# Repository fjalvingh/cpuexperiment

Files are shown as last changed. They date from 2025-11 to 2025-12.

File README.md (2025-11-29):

# Experiments with a am29xx based CPU

The am29xx series of bitslice CPU parts were a big thing when they arrived, and they have been used in many vintage designs. I find them interesting because they are still reasonably simple to understand, and they do replace a large amount of TTL logic for a homebrew CPU. I got a few of these parts from different places and decided to play with them to get an idea on how they work.

To do that the plan is to build some parts for a real CPU. It is not intended to be finished, it is intended to teach me and help me understand these parts, and to help me understand what is important in a CPU design using them.

## Process

NONE OF THIS IS READY FOR ANYTHING!! DO NOT ORDER BOARDS, they will not work ;)

### The ALU, getting to know the am2901

I am starting with the ALU part as I got 4 am2901's in my parts bin ;) I want to make a 16 bit ALU out of them, and the 2901's would also contain the generic register set (r0..r15).
I did consider breadboarding that, but 16 bits is a lot of wires, reliable breadboards are pretty expensive, and I really, *really* did not feel like wiring that all up...
So instead I created a Kicad schematic hoping that I would not be too far off, and I created a PCB using the Autorouter to route most traces so that I would not waste time on that. It is a 2 layer board so making fixes for the mistakes I've undoubtedly made should not be too difficult.

The board has 4x am2901, some glue logic to detect condition codes, a lot of leds to show ALU function inputs, and two sockets for my [8 bit bus to hex display](https://github.com/fjalvingh/8bit-busdisplay) so that we can easily follow what is happening.

The board uses two 40 pin double row pin headers (female) as a connector to a later possible backplane, as these are cheap and relatively reliable. And they make it easy to exercise the board using an Arduino Mega 2560.

A picture of the completed board:

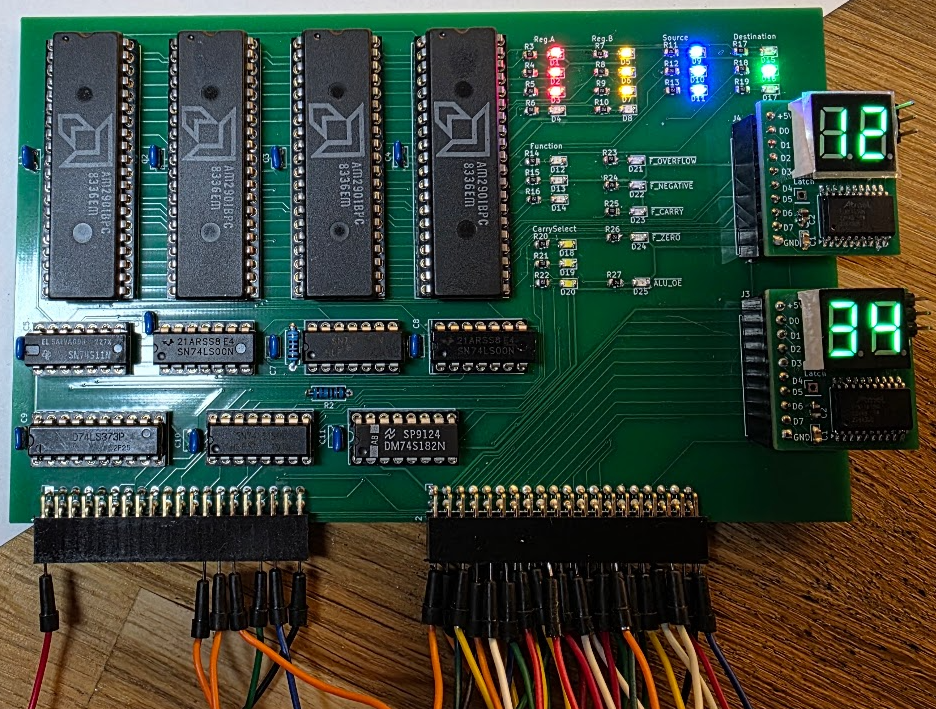
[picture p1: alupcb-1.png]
alu pcb


The wires into the connectors are breadboard patch wires, and they prove to be useless, so the next try is to make real pin header wires to the Arduino.

### Playing with the board

After creating proper cabling between the Arduino and the ALU board:

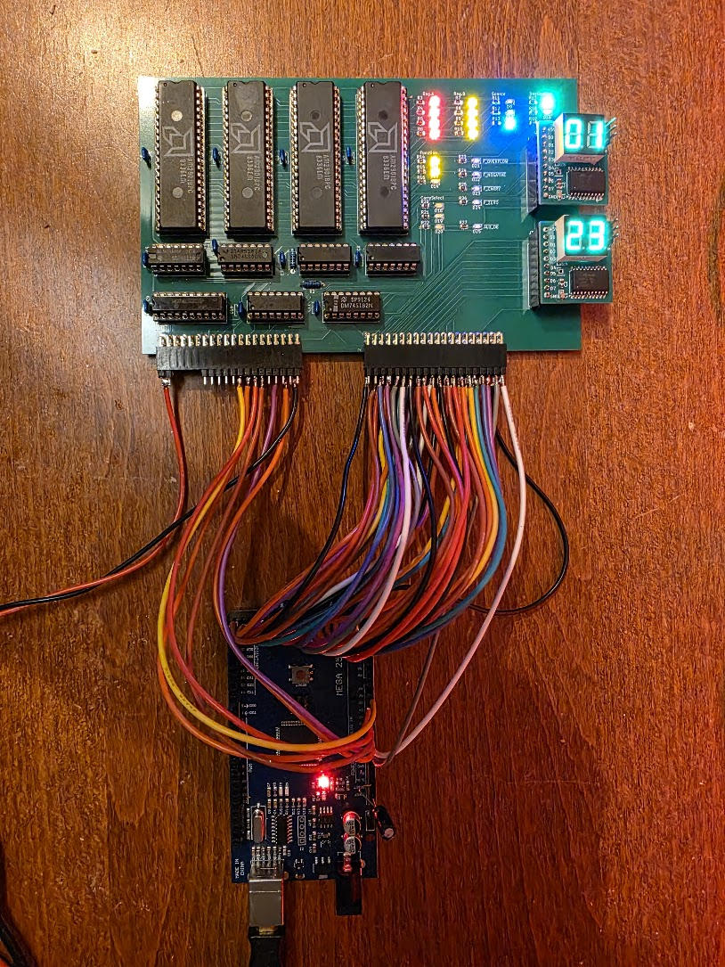
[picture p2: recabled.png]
proper cabling


at least everything worked consistently. But writing Arduino programs makes it a bit hard to do a lot of testing. So the next part is to make the Arduino a slave board that gets commands over USB Serial from a Java program. The Java program sends simple packets consisting of a command code, parameter values and a checksum. The Arduino waits for commands on its bus, decodes the packets, then executes the command. After that it sends either an error packet or a response packet back with any results for the command.

These are the programs under aluboard-controller and aluboard-arduino.

## Progress

* 2025/11/28 Added basic Java GUI and an Arduino program to test the ALU board
* 2025/11/23 Created this Github repo
* 2025/10/18 Started the ALU Kicad design

## Documentation used

I am using the following documents to make sense of everything.

### AM29xx series:
 
* [The AM2900 family data book](documentation/1978_The_Am2900_Family_Data_Book.pdf)
* [The am2901 datasheet](documentation/AM2901-AdvancedMicroDevices.pdf)
* [The am2910 datasheet](documentation/am2910.pdf)
* [Bit Slice microprocessor design](http://www.bitsavers.org/components/amd/bitslice/Mick_Bit-Slice_Microprocessor_Design_1980.pdf) by John Mick and Jim Brick
* [am2910 application note: programming the 2910](documentation/Am2910_apnote_Programming%20the.pdf)
* A more readable [am2901 block diagram](documentation/am2901-blockdiagram.jpg)
* Bit slice design - controllers and ALUs by [Donnamaie White](https://www.donnamaie.com/) - whose site has a lot of other interesting information.
* The "Build a microcomputer" series of appnotes, also [on the site of Donnamaie White, here](https://www.donnamaie.com/AMD_2900.html).
* [A microprogrammed computer](documentation/16-bit%20computer%20book.pdf), also from Donnamaie's site.

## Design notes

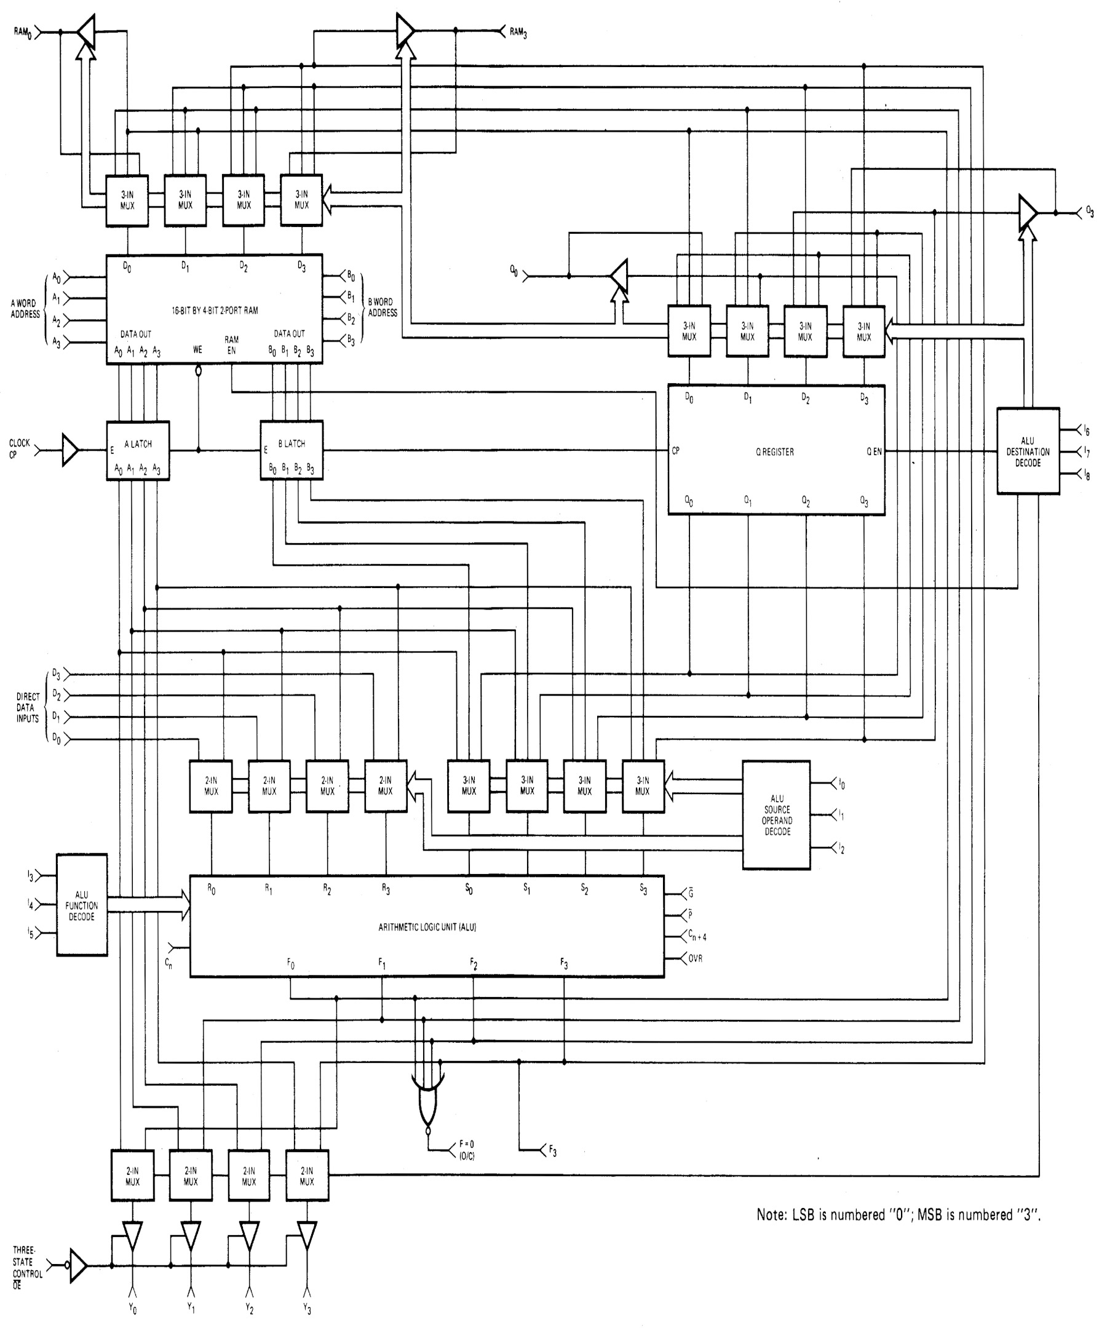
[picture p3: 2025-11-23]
documentation/am2901-blockdiagram.jpg

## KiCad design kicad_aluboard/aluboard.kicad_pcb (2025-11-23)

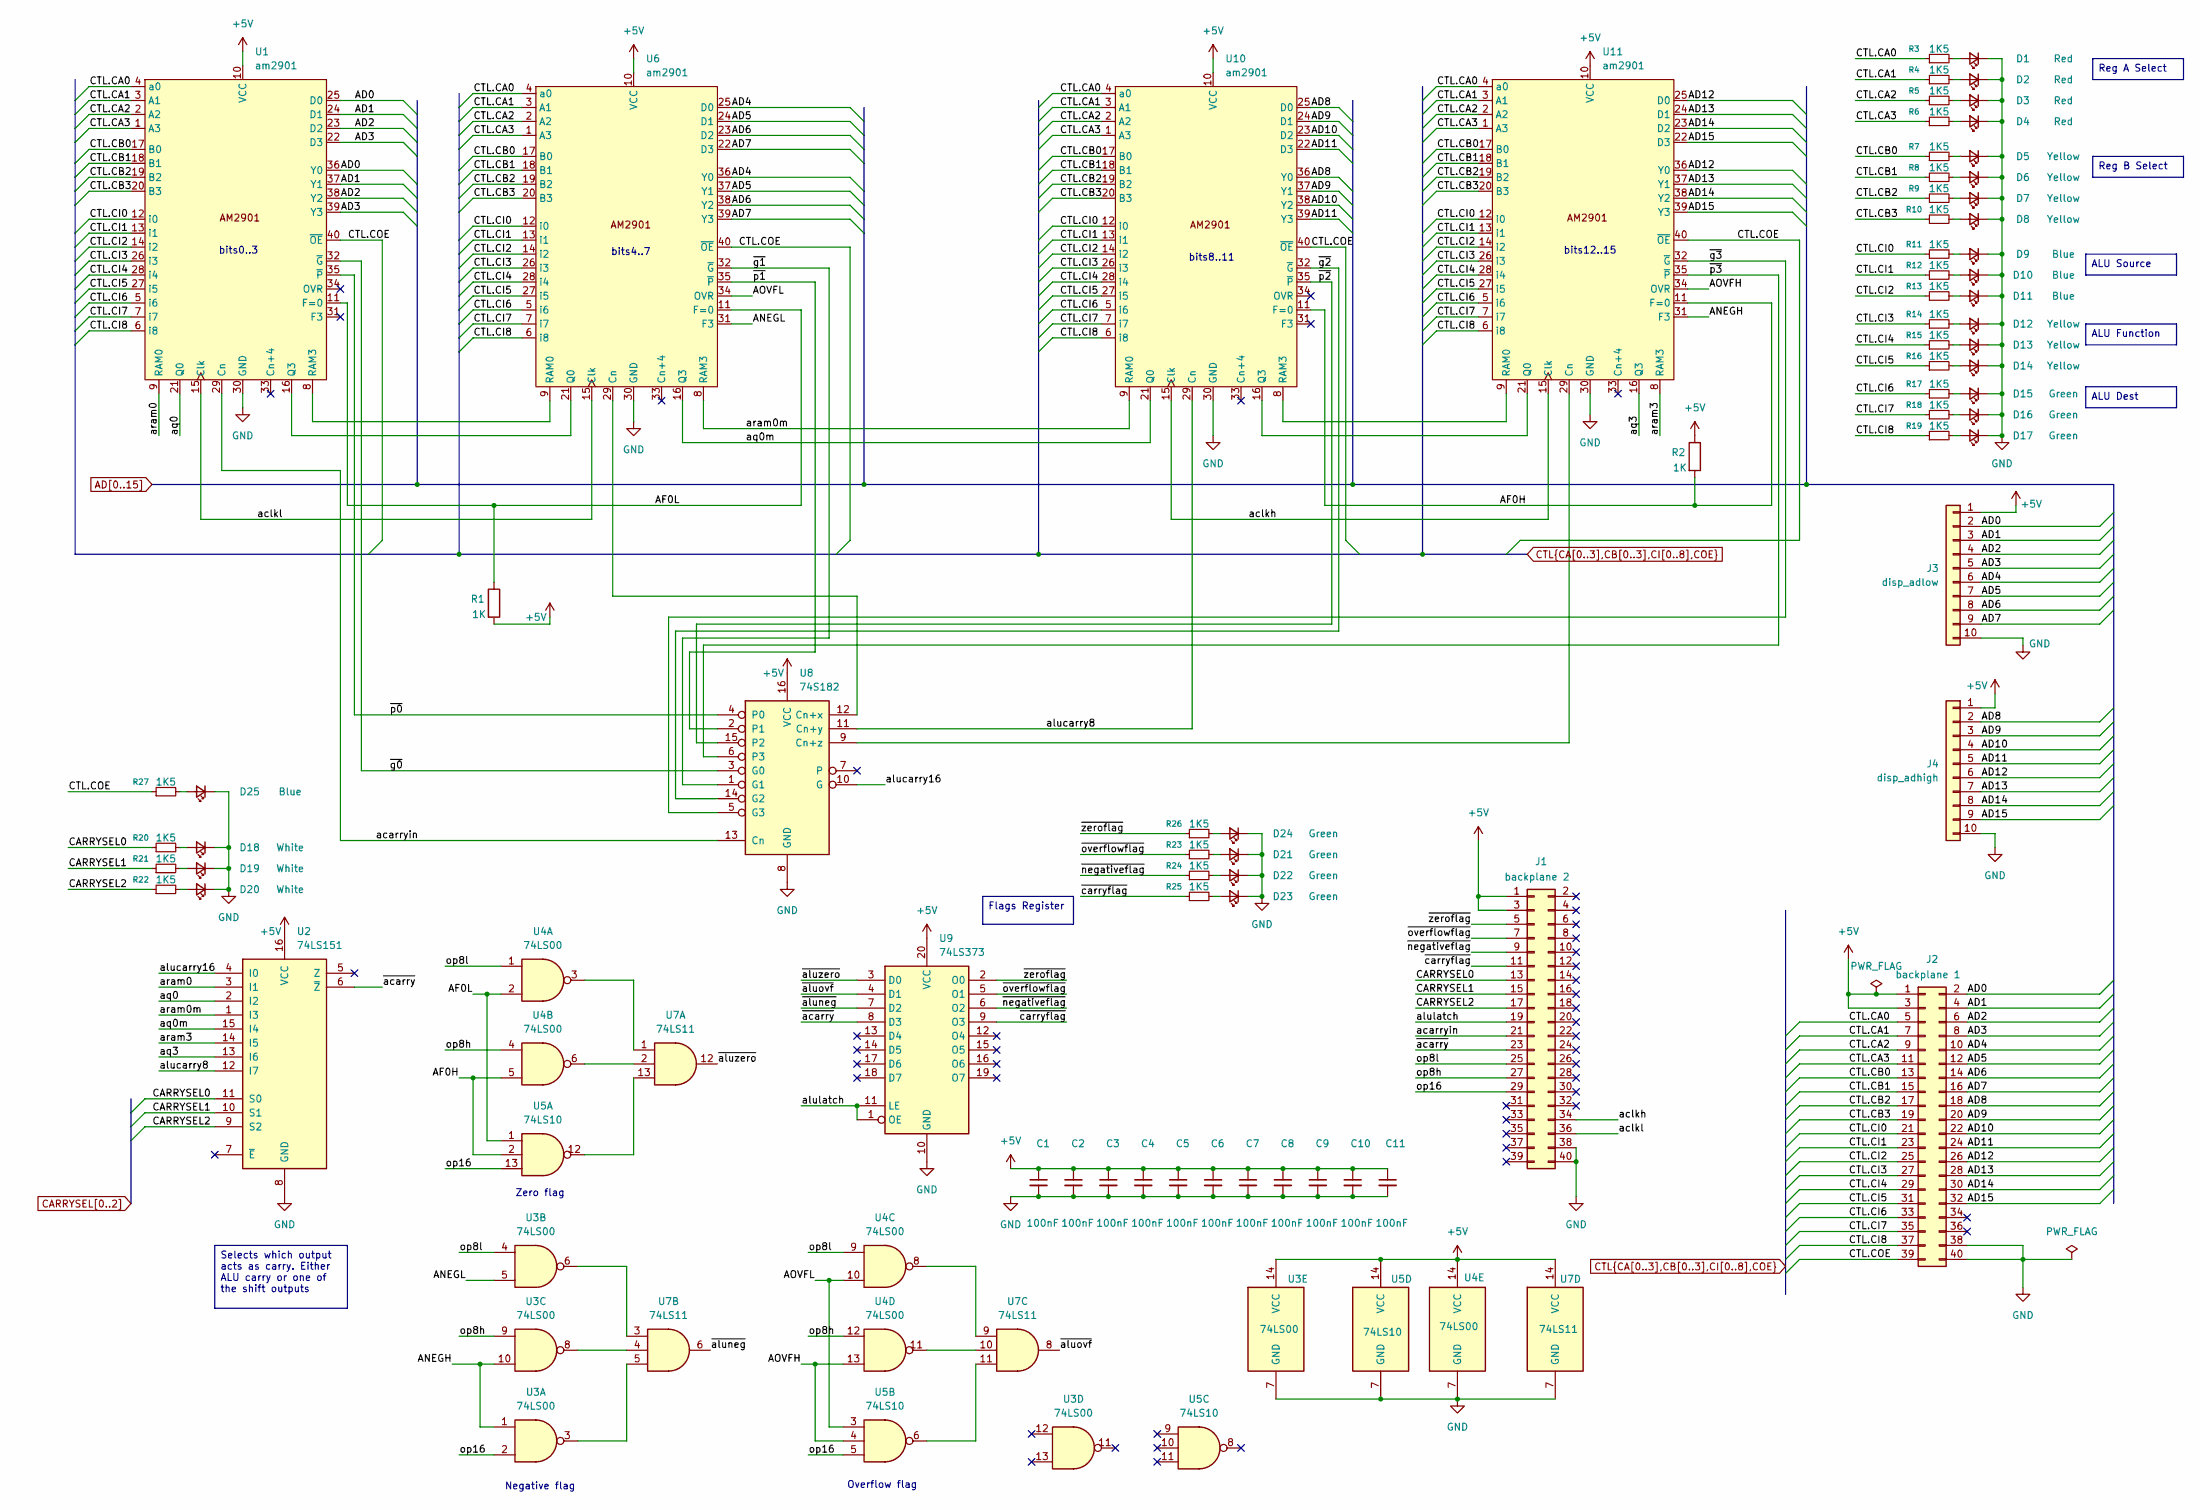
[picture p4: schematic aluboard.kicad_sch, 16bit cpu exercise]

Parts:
C1, C2, C3, C4, C5, C6, C7, C8, C9, C10, C11: 100nF; C_Disc_D3.8mm_W2.6mm_P2.50mm
D1, D2, D3, D4: Red; LED_0805_2012Metric_Pad1.15x1.40mm_HandSolder
D5, D6, D7, D8, D12, D13, D14: Yellow; LED_0805_2012Metric_Pad1.15x1.40mm_HandSolder
D9, D10, D11, D25: Blue; LED_0805_2012Metric_Pad1.15x1.40mm_HandSolder
D15, D16, D17, D21, D22, D23, D24: Green; LED_0805_2012Metric_Pad1.15x1.40mm_HandSolder
D18, D19, D20: White; LED_0805_2012Metric_Pad1.15x1.40mm_HandSolder
J1: backplane 2; PinSocket_2x20_P2.54mm_Horizontal
J2: backplane 1; PinSocket_2x20_P2.54mm_Horizontal
J3: disp_adlow; PinSocket_1x10_P2.54mm_Vertical
J4: disp_adhigh; PinSocket_1x10_P2.54mm_Vertical
R1, R2: 1K; R_Axial_DIN0207_L6.3mm_D2.5mm_P7.62mm_Horizontal
R3, R4, R5, R6, R7, R8, R9, R10, R11, R12, R13, R14, R15, R16, R17, R18, R19, R20, R21, R22, R23, R24, R25, R26, R27: 1K5; R_0805_2012Metric
U1, U6, U10, U11: am2901; DIP-40_W15.24mm_Socket_LongPads
U2: 74LS151; DIP-16_W7.62mm_Socket_LongPads
U3, U4: 74LS00; DIP-14_W7.62mm_Socket_LongPads
U5: 74LS10; DIP-14_W7.62mm_Socket_LongPads
U7: 74LS11; DIP-14_W7.62mm_Socket_LongPads
U8: 74S182; DIP-16_W7.62mm_Socket_LongPads
U9: 74LS373; DIP-20_W7.62mm_Socket_LongPads

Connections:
+5V: C1.1, C2.1, C3.1, C4.1, C5.1, C6.1, C7.1, C8.1, C9.1, C10.1, C11.1, J1.1, J1.3, J2.1, J2.3, J3.1, J4.1, R1.2, R2.1, U1.10 (VCC), U2.16 (VCC), U3.14 (VCC), U4.14 (VCC), U5.14 (VCC), U6.10 (VCC), U7.14 (VCC), U8.16 (VCC), U9.20 (VCC), U10.10 (VCC), U11.10 (VCC)
/AF0H: R2.2, U4.5, U5.2, U10.11 (F=0), U11.11 (F=0)
/AF0L: R1.1, U1.11 (F=0), U4.2, U5.1, U6.11 (F=0)
/ANEGH: U3.1, U3.10, U11.31 (F3)
/ANEGL: U3.5, U6.31 (F3)
/AOVFH: U4.13, U5.4, U11.34 (OVR)
/AOVFL: U4.10, U5.3, U6.34 (OVR)
/acarryin: J1.21, U1.29 (Cn), U8.13 (Cn)
/aclkh: J1.34, U10.15 (Clk), U11.15 (Clk)
/aclkl: J1.36, U1.15 (Clk), U6.15 (Clk)
/alucarry8: U2.12 (I7), U8.11 (Cn+y), U10.29 (Cn)
/alucarry16: U2.4 (I0), U8.10 (G)
/alulatch: J1.19, U9.1 (OE), U9.11 (LE)
/aq0: U1.21 (Q0), U2.2 (I2)
/aq0m: U2.15 (I4), U6.16 (Q3), U10.21 (Q0)
/aq3: U2.13 (I6), U11.16 (Q3)
/aram0: U1.9 (RAM0), U2.3 (I1)
/aram0m: U2.1 (I3), U6.8 (RAM3), U10.9 (RAM0)
/aram3: U2.14 (I5), U11.8 (RAM3)
/op8h: J1.27, U3.9, U4.4, U4.12
/op8l: J1.25, U3.4, U4.1, U4.9
/op16: J1.29, U3.2, U5.5, U5.13
/~acarry: J1.23, U2.6 (~Z), U9.8 (D3)
/~aluneg: U7.6, U9.7 (D2)
/~aluovf: U7.8, U9.4 (D1)
/~aluzero: U7.12, U9.3 (D0)
/~carryflag: J1.11, R25.1, U9.9 (O3)
/~g0: U1.32 (~G), U8.3 (G0)
/~g1: U6.32 (~G), U8.1 (G1)
/~g2: U8.14 (G2), U10.32 (~G)
/~g3: U8.5 (G3), U11.32 (~G)
/~negativeflag: J1.9, R24.1, U9.6 (O2)
/~overflowflag: J1.7, R23.1, U9.5 (O1)
/~p0: U1.35 (~P), U8.4 (P0)
/~p1: U6.35 (~P), U8.2 (P1)
/~p2: U8.15 (P2), U10.35 (~P)
/~p3: U8.6 (P3), U11.35 (~P)
/~zeroflag: J1.5, R26.1, U9.2 (O0)
AD0: J2.2, J3.2, U1.25 (D0), U1.36 (Y0)
AD1: J2.4, J3.3, U1.24 (D1), U1.37 (Y1)
AD2: J2.6, J3.4, U1.23 (D2), U1.38 (Y2)
AD3: J2.8, J3.5, U1.22 (D3), U1.39 (Y3)
AD4: J2.10, J3.6, U6.25 (D0), U6.36 (Y0)
AD5: J2.12, J3.7, U6.24 (D1), U6.37 (Y1)
AD6: J2.14, J3.8, U6.23 (D2), U6.38 (Y2)
AD7: J2.16, J3.9, U6.22 (D3), U6.39 (Y3)
AD8: J2.18, J4.2, U10.25 (D0), U10.36 (Y0)
AD9: J2.20, J4.3, U10.24 (D1), U10.37 (Y1)
AD10: J2.22, J4.4, U10.23 (D2), U10.38 (Y2)
AD11: J2.24, J4.5, U10.22 (D3), U10.39 (Y3)
AD12: J2.26, J4.6, U11.25 (D0), U11.36 (Y0)
AD13: J2.28, J4.7, U11.24 (D1), U11.37 (Y1)
AD14: J2.30, J4.8, U11.23 (D2), U11.38 (Y2)
AD15: J2.32, J4.9, U11.22 (D3), U11.39 (Y3)
CARRYSEL0: J1.13, R20.1, U2.11 (S0)
CARRYSEL1: J1.15, R21.1, U2.10 (S1)
CARRYSEL2: J1.17, R22.1, U2.9 (S2)
CTL.CA0: J2.5, R3.1, U1.4 (a0), U6.4 (a0), U10.4 (a0), U11.4 (a0)
CTL.CA1: J2.7, R4.1, U1.3 (A1), U6.3 (A1), U10.3 (A1), U11.3 (A1)
CTL.CA2: J2.9, R5.1, U1.2 (A2), U6.2 (A2), U10.2 (A2), U11.2 (A2)
CTL.CA3: J2.11, R6.1, U1.1 (A3), U6.1 (A3), U10.1 (A3), U11.1 (A3)
CTL.CB0: J2.13, R7.1, U1.17 (B0), U6.17 (B0), U10.17 (B0), U11.17 (B0)
CTL.CB1: J2.15, R8.1, U1.18 (B1), U6.18 (B1), U10.18 (B1), U11.18 (B1)
CTL.CB2: J2.17, R9.1, U1.19 (B2), U6.19 (B2), U10.19 (B2), U11.19 (B2)
CTL.CB3: J2.19, R10.1, U1.20 (B3), U6.20 (B3), U10.20 (B3), U11.20 (B3)
CTL.CI0: J2.21, R11.1, U1.12 (i0), U6.12 (i0), U10.12 (i0), U11.12 (i0)
CTL.CI1: J2.23, R12.1, U1.13 (i1), U6.13 (i1), U10.13 (i1), U11.13 (i1)
CTL.CI2: J2.25, R13.1, U1.14 (i2), U6.14 (i2), U10.14 (i2), U11.14 (i2)
CTL.CI3: J2.27, R14.1, U1.26 (i3), U6.26 (i3), U10.26 (i3), U11.26 (i3)
CTL.CI4: J2.29, R15.1, U1.28 (i4), U6.28 (i4), U10.28 (i4), U11.28 (i4)
CTL.CI5: J2.31, R16.1, U1.27 (i5), U6.27 (i5), U10.27 (i5), U11.27 (i5)
CTL.CI6: J2.33, R17.1, U1.5 (i6), U6.5 (i6), U10.5 (i6), U11.5 (i6)
CTL.CI7: J2.35, R18.1, U1.7 (i7), U6.7 (i7), U10.7 (i7), U11.7 (i7)
CTL.CI8: J2.37, R19.1, U1.6 (i8), U6.6 (i8), U10.6 (i8), U11.6 (i8)
CTL.COE: J2.39, R27.1, U1.40 (~OE), U6.40 (~OE), U10.40 (~OE), U11.40 (~OE)
GND: C1.2, C2.2, C3.2, C4.2, C5.2, C6.2, C7.2, C8.2, C9.2, C10.2, C11.2, D1.1 (K), D2.1 (K), D3.1 (K), D4.1 (K), D5.1 (K), D6.1 (K), D7.1 (K), D8.1 (K), D9.1 (K), D10.1 (K), D11.1 (K), D12.1 (K), D13.1 (K), D14.1 (K), D15.1 (K), D16.1 (K), D17.1 (K), D18.1 (K), D19.1 (K), D20.1 (K), D21.1 (K), D22.1 (K), D23.1 (K), D24.1 (K), D25.1 (K), J1.38, J1.40, J2.38, J2.40, J3.10, J4.10, U1.30 (GND), U2.8 (GND), U3.7 (GND), U4.7 (GND), U5.7 (GND), U6.30 (GND), U7.7 (GND), U8.8 (GND), U9.10 (GND), U10.30 (GND), U11.30 (GND)
unnamed: D1.2 (A), R3.2
unnamed: D2.2 (A), R4.2
unnamed: D3.2 (A), R5.2
unnamed: D4.2 (A), R6.2
unnamed: D5.2 (A), R7.2
unnamed: D6.2 (A), R8.2
unnamed: D7.2 (A), R9.2
unnamed: D8.2 (A), R10.2
unnamed: D9.2 (A), R11.2
unnamed: D10.2 (A), R12.2
unnamed: D11.2 (A), R13.2
unnamed: D12.2 (A), R14.2
unnamed: D13.2 (A), R15.2
unnamed: D14.2 (A), R16.2
unnamed: D15.2 (A), R17.2
unnamed: D16.2 (A), R18.2
unnamed: D17.2 (A), R19.2
unnamed: D18.2 (A), R20.2
unnamed: D19.2 (A), R21.2
unnamed: D20.2 (A), R22.2
unnamed: D21.2 (A), R23.2
unnamed: D22.2 (A), R24.2
unnamed: D23.2 (A), R25.2
unnamed: D24.2 (A), R26.2
unnamed: D25.2 (A), R27.2
unnamed: U1.16 (Q3), U6.21 (Q0)
unnamed: U1.8 (RAM3), U6.9 (RAM0)
unnamed: U3.3, U7.5
unnamed: U3.6, U7.3
unnamed: U3.8, U7.4
unnamed: U4.3, U7.1
unnamed: U4.6, U7.2
unnamed: U4.8, U7.9
unnamed: U4.11, U7.10
unnamed: U5.6, U7.11
unnamed: U5.12, U7.13
unnamed: U6.29 (Cn), U8.12 (Cn+x)
unnamed: U10.16 (Q3), U11.21 (Q0)
unnamed: U10.8 (RAM3), U11.9 (RAM0)
unnamed: U8.9 (Cn+z), U11.29 (Cn)

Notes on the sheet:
Overflow flag
bits8..11
bits0..3
Zero flag
bits4..7
bits12..15
Negative flag
Selects which output acts as carry. Either ALU carry or one of the shift outputs
Reg B Select
Reg A Select
Flags Register
ALU Function
ALU Dest
ALU Source

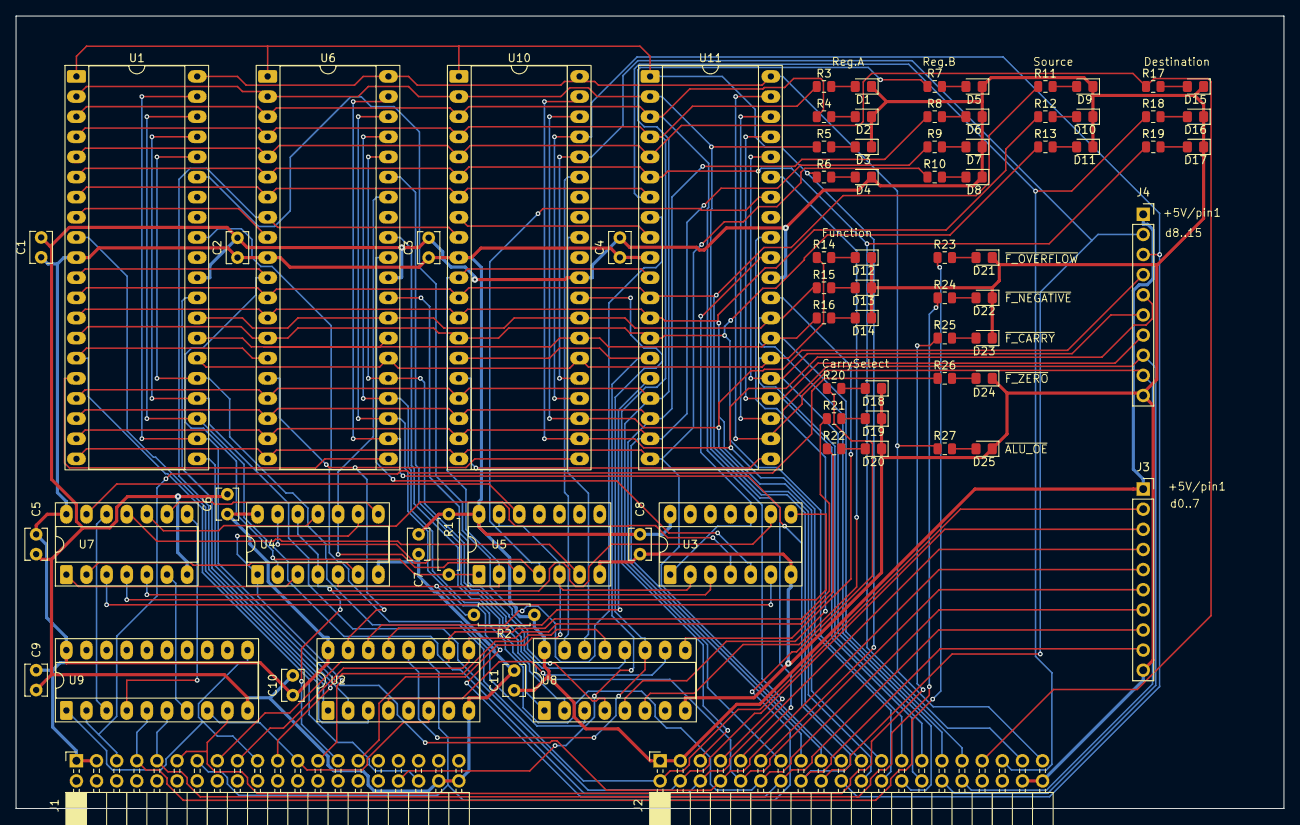
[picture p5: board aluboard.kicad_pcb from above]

Board: 2 copper layers, 160.0 x 100.0 mm, 79 parts (1 on the bottom side), 116 nets.

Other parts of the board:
logo: LOGO

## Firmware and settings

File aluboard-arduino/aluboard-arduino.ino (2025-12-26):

#include <stdarg.h>

/********************************************************/
/*  ALU Board connections to Arduino                    */
/********************************************************/

#define ARDUINO_A0  54        // Pin number to use A0 as digital port

#define AD0         22              // AD0..15 ALU input/result

#define CTL_CA0     (AD0 + 16)      // Start of CA0 assignments (38)
#define CTL_CB0     (CTL_CA0 + 4)   // (42)
#define CTL_CI0     (CTL_CB0 + 4)   // Control signals (46) 

#define CTL_OE      (ARDUINO_A0 + 1)     // OE pin is on analog 1. Analog 0 is CTL.CI8, a control signal for the alu.

#define CTL_CLKAH   (ARDUINO_A0 + 2)
#define CTL_CLKAL   (ARDUINO_A0 + 3)

#define CTL_OP16    (ARDUINO_A0 + 4)
#define CTL_OP8H    (ARDUINO_A0 + 5)
#define CTL_OP8L    (ARDUINO_A0 + 6)

#define ACARRYIN    (ARDUINO_A0 + 7)      // ALU Carry in
#define FLAGSLATCH  (ARDUINO_A0 + 8)      // Flags register latch

#define CARRYSEL2   (ARDUINO_A0 + 9)      // Carry flag source. Watch out: reversed!
#define CARRYSEL1   (ARDUINO_A0 + 10)
#define CARRYSEL0   (ARDUINO_A0 + 11)

#define FLGCARRYL   (ARDUINO_A0 + 12)     // Carry flag, L active
#define FLGNEGL     (ARDUINO_A0 + 13)
#define FLGOVFL     (ARDUINO_A0 + 14)
#define FLGZEROL    (ARDUINO_A0 + 15)

#define CLKN        HIGH
#define CLKA        LOW

/********************************************************/
/*  Mode enums for both am2901 and ALU board.           */
/********************************************************/


enum CarrySel {
  Alu16,                  // 16 bit carry from ALU
  ARam0,                  // Carry from lhs shift on register
  AQ0,                    // Carry from low shift on Q register
  ARam0m,                 // Carry from shift on 8 bit middle of register
  AQ0m,                   // Carry from shift on middle of Q register
  ARam3,                  // Carry from high shift register
  AQ3,                    // Carry from high Q
  Alu8,                   // Alu carry from lower 8 bits
};

enum AluSource {
  SrcAQ,
  SrcAB,
  Src0Q,
  Src0B,
  Src0A,
  SrcDA,
  SrcDQ,
  SrcD0,
};

enum AluFunction {
  FnAdd,
  FnSubR,
  FnSubS,
  FnOr,
  FnAnd,
  FnNotRS,
  FnExOr,
  FnExNor,
};

enum AluDest {
  DstQReg,
  DstNop,
  DstRamA,
  DstRamF,
  DstRamQD,
  DstRamD,
  DstRamQU,
  DstRamU,
};

enum AluOpType {
  Op16,
  Op8L,
  Op8H
};

enum FlagsLatch {
  /** Keep values inside the latch, do not follow inputs */
  FlagLatchHold,
  /** Let input values flow to outputs */
  FlagLatchOpen             // Man, C is a shit language.
};

/**
 * Set pinMode for all AD lines to in- or out
 */
void setADMode(int mode) {
  for(int i = 0; i < 16; i++) {
    pinMode(AD0 + i, mode);
  }
}

void bitsWrite(int startPin, int bitCount, int value) {
  for(int i = 0; i < bitCount; i++) {
    if(value & (1 << i)) {
      digitalWrite(startPin + i, HIGH);
    } else {
      digitalWrite(startPin + i, LOW);
    }
  }
}

/**
 * Read data from AD0..AD15.
 */
int readData() {
  setADMode(INPUT);
  
  int result = 0;
  for(int i = 0; i < 16; i++) {
    int val = digitalRead(AD0 + i);
    if(val != 0) {
        result |= 1 << i;
    }
  }
  return result;
}

/**
 * Write data to AD0..15. The data stays after the call. The call ensures that OE is HIGH (negated).
 */
void writeData(int value) {
  digitalWrite(CTL_OE, HIGH);             // Make sure OE is negated
  setADMode(OUTPUT);
  bitsWrite(AD0, 16, value);
}

/**
 * Set a value for CA0..3, selecting ALU register port A
 */
void setAluPortA(int value) {
  bitsWrite(CTL_CA0, 4, value);
}
void setAluPortB(int value) {
  bitsWrite(CTL_CB0, 4, value);
}
/**
 * Set the alu source code (i0..2) 
 */
void setAluSrc(AluSource code) {
  bitsWrite(CTL_CI0, 3, code);
}
void setAluFunction(AluFunction code) {
  bitsWrite(CTL_CI0 + 3, 3, code);
}
void setAluDest(AluDest code) {
  bitsWrite(CTL_CI0 + 6, 3, code);
}

/**
 * Pulse the CLOCK line.
 * Description:
 * - when CLK is HIGH the A and B latches are open, providing 
 *   data from the registers to the ALU as-is. When CLK is LOW
 *   the latches are holding the last data, and data is WRITTEN
 *   into the register designated by B IF a RAM destination is chosen.
 * - Data gets clocked in Q on the upward edge of the clock.
 */
void pulseOperation(AluOpType op, bool latchFlags) {
  switch(op) {
    case Op16:
      digitalWrite(CTL_OP16, HIGH);
      digitalWrite(CTL_OP8H, LOW);
      digitalWrite(CTL_OP8L, LOW);
      break;

    case Op8H:
      digitalWrite(CTL_OP16, LOW);
      digitalWrite(CTL_OP8H, HIGH);
      digitalWrite(CTL_OP8L, LOW);
      break;

    case Op8L:
      digitalWrite(CTL_OP16, LOW);
      digitalWrite(CTL_OP8H, LOW);
      digitalWrite(CTL_OP8L, HIGH);
      break;
  }
  //-- Now pulse the required clock lines
  if(op == Op16 || op == Op8L)
    digitalWrite(CTL_CLKAL, LOW);              

  if(op == Op16 || op == Op8H)
    digitalWrite(CTL_CLKAH, LOW);
  delay(1);

  //-- We latch the flags while the register data is latched, because that represents the
  //-- real state. Once the clock is high the data passes through, with the same operation
  //-- code, so in effect the data on the bus would be the result of the same operation as
  //-- before, a second time.
  if(latchFlags) {
    setAluLatch(FlagLatchOpen);
    delayMicroseconds(100);
    setAluLatch(FlagLatchHold);
  }
  
  digitalWrite(CTL_CLKAL, HIGH);                 //  Low: keep data in latches
  digitalWrite(CTL_CLKAH, HIGH);
  // digitalWrite(CTL_OP16, LOW);
  // digitalWrite(CTL_OP8H, LOW);
  // digitalWrite(CTL_OP8L, LOW);
}

void pulseClockLH() {
    digitalWrite(CTL_CLKAL, LOW);               // Write data to RAM if DEST is RAM
    digitalWrite(CTL_CLKAH, LOW);
    digitalWrite(CTL_CLKAL, HIGH);            
    digitalWrite(CTL_CLKAH, HIGH);
}

/**
 * Set Alu register 0..15 to the specified value
 */
void setAluReg(int reg, int value) {
  setAluPortB(reg);
  writeData(value);
  setAluSrc(SrcD0);                     // Read data from D bus and other part is zero
  setAluFunction(FnOr);                 // Add D plus 0
  setAluDest(DstRamF);                  // Alu result (F) to B
  
  //-- Pulse clock to LOW to enter data into the register.
  pulseClockLH();
  setAluDest(DstNop);
  // pulseOperation(Op16, false);
  // delay(2);
  setADMode(INPUT);
}

/**
 * Set the Q reg to the spec'd
 */
void setQReg(int value) {
  writeData(value);
  setAluSrc(SrcD0);                     // Read data from D bus and other part is zero
  setAluFunction(FnOr);                 // Add D plus 0
  setAluDest(DstQReg);                  // Alu result (F) to Q
  pulseOperation(Op16, false);
  setAluDest(DstNop);
  // delay(2);
  setADMode(INPUT);
}


void setOE(boolean on) {
  digitalWrite(CTL_OE, on ? LOW : HIGH);
}

void setCarrySel(CarrySel sel) {
  digitalWrite(CARRYSEL0, sel & 0x1 ? HIGH : LOW);
  digitalWrite(CARRYSEL1, sel & 0x2 ? HIGH : LOW);
  digitalWrite(CARRYSEL2, sel & 0x4 ? HIGH : LOW);
}

/**
*/
void setAluLatch(FlagsLatch val) {
  digitalWrite(FLAGSLATCH, val == FlagLatchOpen);   // Open is a 1 on that chip
}

void setAluCarryIn(boolean val) {
  digitalWrite(ACARRYIN, val);
}

/*
 * Read the flag register values as a bit pattern.
*/
int readFlags() {
  int carry = digitalRead(FLGCARRYL) == 0;
  int neg = digitalRead(FLGNEGL) == 0;
  int ovf = digitalRead(FLGOVFL) == 0;
  int zero = digitalRead(FLGZEROL) == 0;

  char buf[60];
  sprintf(buf, "z=%d,c=%d,n=%d,o=%d\n", zero, carry, neg, ovf);
  Serial.print(buf);

  return (zero << 3)
    | (ovf << 2)
    | (neg << 1)
    | carry;
}


/********************************************************/
/*  Serial command reader                               */
/********************************************************/

#define CMD_ERROR     0x01
#define CMD_REGISTERS 0x02
#define CMD_SETREGS   0x03
#define CMD_ALUOP     0x04
#define CMD_INITREGS  0x05
#define CMD_ZEROREGS  0x06

uint8_t readBuffer[259];
int readIndex;
int readLen;

/**
 * Read one byte from the packet.
*/
int rdByte() {
  if(readIndex >= readLen)
    return -1;
  return readBuffer[readIndex++];
}

int rdWord() {
  if(readIndex + 1 >= readLen)
    return -1;
  int hi = readBuffer[readIndex++];
  int lo = readBuffer[readIndex++];
  return hi << 8 | lo;
}

boolean rdEof() {
  return readIndex >= readLen;
}


/********************************************************/
/*  Packet writer                                       */
/********************************************************/
#define WRITEINDEX_MAX  (2 + 1 + 255)         // Max. write size: lead-in, length, 255 bytes rest

uint8_t writeBuffer[WRITEINDEX_MAX + 2];      // Plus 2 bytes for checksum
int writeIndex;


void pktStart(int command) {
  writeBuffer[0] = 0xaa;
  writeBuffer[1] = 0x55;
  writeBuffer[2] = 0;           // Len will be patched in later
  writeBuffer[3] = (command >> 8) & 0xff;
  writeBuffer[4] = (command & 0xff);
  writeIndex = 5;               // First packet data byte
}

void pktByte(int v) {
  if(writeIndex >= WRITEINDEX_MAX)
    return;
  writeBuffer[writeIndex++] = v;
}

void pktWord(int v) {
  if(writeIndex + 1 >= WRITEINDEX_MAX)
    return;
  writeBuffer[writeIndex++] = v >> 8;
  writeBuffer[writeIndex++] = v & 0xff;
}

void pktString(char* str) {
  while(writeIndex < WRITEINDEX_MAX && *str != 0) {
    writeBuffer[writeIndex++] = *str++;
  }
}

void pktFinish() {
  int len = writeIndex - 3;           // -3 = lead-in + len
  writeBuffer[2] = len;               // Put it where it belongs
  int sum = 0;
  for(int i = 3; i < writeIndex; i++) {
    sum += writeBuffer[i];
  }
  writeBuffer[writeIndex++] = sum >> 8;
  writeBuffer[writeIndex++] = sum & 0xff;
}

void pktSend() {
  pktFinish();
  Serial.write(writeBuffer, writeIndex);
}


/********************************************************/
/*  Command functions                                   */
/********************************************************/

void replyError(char* message, ...) {
  va_list args;
  va_start(args, message);
  char buf[256];

  vsprintf(buf, message, args);
  pktStart(CMD_ERROR);
  pktString(buf);
  pktSend();
}

/**
 * Output Packet format: just one word per register.
 */
void replyRegisters() {
  pktStart(CMD_REGISTERS);
  
  //-- Clock needs to be HIGH to allow the A-B latches to pass data
  digitalWrite(CTL_CLKAL, HIGH);
  digitalWrite(CTL_CLKAH, HIGH);

  setAluFunction(FnOr);
  setAluDest(DstNop);
  setAluSrc(Src0A);               // 0, A as sources
  setOE(true);

  //-- Read all ALU registers one by one and output on F (data)
  for(int i = 0; i < 16; i++) {
    setAluPortA(i);
    setAluPortB(i);
    pulseOperation(Op16, false);
    int rv = readData();
    // delay(100);
    pktWord(rv);
  }

  //-- Read the Q register
  setAluSrc(Src0Q);
  pulseOperation(Op16, false);
  int rv = readData();
  pktWord(rv);

  //-- And read the flags
  int f = readFlags();
  pktWord(f);

  pktSend();
}

void replyRegistersOld() {
  pktStart(CMD_REGISTERS);
  
  //-- Clock needs to be HIGH to allow the A-B latches to pass data
  digitalWrite(CTL_CLKAL, HIGH);
  digitalWrite(CTL_CLKAH, HIGH);

  setAluFunction(FnOr);
  setAluDest(DstNop);
  setAluSrc(Src0A);               // 0, A as sources
  setOE(true);

  //-- Read all ALU registers one by one and output on F (data)
  for(int i = 0; i < 16; i++) {
    setAluPortA(i);
    setAluPortB(i);
    pulseOperation(Op16, false);
    int rv = readData();
    // delay(100);
    pktWord(rv);
  }

  //-- Read the Q register
  setAluSrc(Src0Q);
  pulseOperation(Op16, false);
  int rv = readData();
  pktWord(rv);

  //-- And read the flags
  int f = readFlags();
  pktWord(f);

  pktSend();
}


/**
 * Input packet: one word per register.
 * Output packet: empty.
 */
void cmdSetRegisters() {
  for(int i = 0; i < 16; i++) {
    int regval = rdWord();
    setAluReg(i, regval);
  }
  int qval = rdWord();
  setQReg(qval);

  pktStart(CMD_SETREGS);
  pktSend();
}

/**
 * Input packet: [porta][portb][i0..8][opsz][carrysel][carryin]{[datain]}.
 * Output packet: empty
 */
void cmdAluOperation() {
  int porta = rdByte();
  int portb = rdByte();
  int ictl = rdWord();
  int opsz = rdByte();
  int carrysel = rdByte();
  int carryin = rdByte();
  boolean withData = !rdEof();
  int data = 0;
  if(withData)
    data = rdWord();

  // all of the packet done.
  setAluPortA(porta);
  setAluPortB(portb);

  int src = ictl & 0x7;
  setAluSrc(src);
  int fn = (ictl >> 3) & 0x7;
  setAluFunction(fn);
  int dst = (ictl >> 6) & 0x7;
  setAluDest(dst);
  setCarrySel(carrysel);
  setAluCarryIn(carryin);

  if(withData)
    writeData(data);
  pulseOperation(opsz, true);         // Pulse clocks, do the op, latch flags

  char buf[128];
  sprintf(buf, "aluop: a=%d,b=%d,src=%d,fn=%d,dst=%d,ictl=%x", porta, portb, src, fn, dst, ictl);
  Serial.println(buf);

  pktStart(CMD_ALUOP);
  pktSend();
}

void cmdInitRegs() {
  testSetRegisters();
  pktStart(CMD_INITREGS);
  pktSend();
}

void cmdZeroRegisters() {
  for(int i = 0; i < 16; i++) {
    setAluReg(i, 0);
  }
  setQReg(0);
  pktStart(CMD_ZEROREGS);
  pktSend();
}

/********************************************************/
/*  Serial receive loop                                 */
/********************************************************/
/**
 * Read a serial packet, then execute the related command.
 */
void packetReader() {
  //-- Wait for the 0xaa 0x55 lead-in
  int phase = 0;
  while(true) {
    if(Serial.available()) {
      // Serial.println("Available");
      int r = Serial.readBytes(readBuffer, 3);
      if(r == 3) {
        if(readBuffer[0] == 0xaa && readBuffer[1] == 0x55)
          break;
      }
      // if(r > 0) {
      //   Serial.println("Gotcha");
      // }
    }
  }

  Serial.println("hdr");
  //-- Lead-in received, next is length
  int len = readBuffer[2];
  int rc = Serial.readBytes(readBuffer, len + 2);               // Read the packet and include the checksum
  if(rc != len + 2) {                                                // Incomplete?
    Serial.println("badlen");
    return;
  }

  //-- Check the sum
  int sum = 0;
  for(int i = 0; i < len; i++) {
    sum += readBuffer[i];
  }
  unsigned int psum = ((int)readBuffer[len] << 8) | (int)readBuffer[len + 1];
  if(sum != psum) {
    //-- Checksum error, bail out
    Serial.print("Badsum ");
    Serial.print(psum, 16);
    Serial.print(" exp ");
    Serial.println(sum, 16);
    return;
  }

  //-- All is well. We have a packet.. Initialize the read data.
  readIndex = 0;
  readLen = len;

  //-- Decode the command
  int command = rdWord();
  switch(command) {
    default:
      replyError("command %d??", command);
      break;

    case CMD_REGISTERS:
      replyRegisters();
      break;

    case CMD_SETREGS:
      cmdSetRegisters();
      break;

    case CMD_ALUOP:
      cmdAluOperation();
      break;  

    case CMD_INITREGS:
      cmdInitRegs();
      break;

    case CMD_ZEROREGS:
      cmdZeroRegisters();
      break;
  }
}

int vals[] = {
  0x1234, // 0
  0x2345,
  0x3456,
  0x4567,
  0x5678,
  0x6789,
  0x789a,
  0x89ab,
  0x9abc, // 8
  0xabcd,
  0xbcde,
  0xcdef,
  0xdef0,
  0xef01,
  0xf012,
  0x0123,
};

void testSetRegisters() {
  for(int i = 0; i < 16; i++) {
    setAluReg(i, vals[i]);
  }
}


void setup() {
  pinMode(CTL_OE, OUTPUT);
  digitalWrite(CTL_OE, HIGH);               // Disable AD0..15 outputs

  for(int i = 0; i < 4; i++)
    pinMode(CTL_CA0 + i, OUTPUT);
  for(int i = 0; i < 4; i++)
    pinMode(CTL_CB0 + i, OUTPUT);
  for(int i = 0; i < 9; i++)
    pinMode(CTL_CI0 + i, OUTPUT);
  pinMode(CTL_OP16, OUTPUT);
  pinMode(CTL_OP8L, OUTPUT);
  pinMode(CTL_OP8H, OUTPUT);

  pinMode(CTL_CLKAL, OUTPUT);
  pinMode(CTL_CLKAH, OUTPUT);
  digitalWrite(CTL_CLKAL, LOW);             // Latched A and B
  digitalWrite(CTL_CLKAH, LOW);

  pinMode(ACARRYIN, OUTPUT);
  digitalWrite(ACARRYIN, LOW);              // Carry in 0

  pinMode(FLAGSLATCH, OUTPUT);
  // digitalWrite(FLAGSLATCH, HIGH);           // Let flag values roll through (not latched)
  digitalWrite(FLAGSLATCH, LOW);

  pinMode(CARRYSEL0, OUTPUT);
  pinMode(CARRYSEL1, OUTPUT);
  pinMode(CARRYSEL2, OUTPUT);
  digitalWrite(CARRYSEL0, LOW);
  digitalWrite(CARRYSEL1, LOW);
  digitalWrite(CARRYSEL2, LOW);

  pinMode(FLGCARRYL, INPUT);
  pinMode(FLGNEGL, INPUT);
  pinMode(FLGOVFL, INPUT);
  pinMode(FLGZEROL, INPUT);

  Serial.begin(19200);
  Serial.setTimeout(5000);
}

void loop() {
  testSetRegisters();

  for(;;) {
    packetReader();
  }

}

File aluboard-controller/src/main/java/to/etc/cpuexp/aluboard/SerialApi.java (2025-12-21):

package to.etc.cpuexp.aluboard;

import com.fazecast.jSerialComm.SerialPort;

import java.io.ByteArrayOutputStream;

final public class SerialApi {
	private final SerialPort m_port;

	private ByteArrayOutputStream m_pb;

	/** Response code that indicates an error */
	static private final int CMD_ERROR = 0x01;

	/** Get all register value */
	static private final int CMD_REGISTERS = 0x02;

	static private final int CMD_SETREGS = 0x03;

	static private final int CMD_ALUOPERATION = 0x04;

	static private final int CMD_INITREGS = 0x05;

	static private final int CMD_ZEROREGS = 0x06;

	static public final int FF_ZERO = 0x08;
	static public final int FF_OVF = 0x04;
	static public final int FF_NEG = 0x02;
	static public final int FF_C = 0x01;


	private int m_packetLen;

	private int m_lastCommand;

	public SerialApi(SerialPort port) {
		m_port = port;
	}

	/**
	 * Tell the Arduino to read all registers and send their content.
	 */
	public int[] getRegisters() {
		startPacket(CMD_REGISTERS);
		transactPacket();
		int[] regs = new int[18];						// 0..15, Q, Flags
		for(int i = 0; i < regs.length; i++) {
			regs[i] = readWord();
		}
		return regs;
	}

	public void writeRegisters(int[] registers) {
		startPacket(CMD_SETREGS);
		for(int i = 0; i < 17; i++) {					// r0..15 and Q
			writeWord(registers[i]);
		}
		transactPacket();                                // The command has no data in the response
	}

	public void registersInit() {
		startPacket(CMD_INITREGS);
		transactPacket();
	}

	public void registersZero() {
		startPacket(CMD_ZEROREGS);
		transactPacket();
	}

	/**
	 * Packet format:
	 * <pre>
	 *  Input packet: [porta][portb][i0..8][opsz][carrysel][carryin]{[datain]}.
	 * </pre>
	 */
	public void aluAction(int porta, int portb, int srcCode, int fnCode, int dstCode, int szCode, int carrySel, int carry) {
		startPacket(CMD_ALUOPERATION);
		writeByte(porta);
		writeByte(portb);

		//-- Construct the i0..8 value
		int i08 = (srcCode & 0x7)
			| ((fnCode & 0x7) << 3)
			| ((dstCode & 0x7) << 6);
		writeWord(i08);
		writeByte(szCode);
		writeByte(carrySel);                    // For now, carrysel
		writeByte(carry);                       // And carry
		transactPacket();
	}

	/*----------------------------------------------------------------------*/
	/*	CODING:	Exchanging packets											*/
	/*----------------------------------------------------------------------*/

	/**
	 * Send a command, then wait for the result. Return the result packet.
	 */
	private void transactPacket() {
		byte[] packet = finishPacket();

		int tries = 0;
		long ets = System.currentTimeMillis() + RETRY_TIMEOUT;
		RuntimeException lastException = null;
		for(; ; ) {
			sendPacket(packet);

			try {
				receivePacket();

				//-- Read the command response code from the packet
				int responseCode = readWord();
				if(responseCode == CMD_ERROR) {
					String message = readString();
					throw new RemoteErrorException(message);
				} else if(responseCode != m_lastCommand) {
					throw new MessageException("Out-of-sync reply: received response code " + responseCode + " for command " + m_lastCommand);
				}
				return;
			} catch(RemoteErrorException e) {
				System.out.println("Remote error: " + e.getMessage());
				lastException = e;
			} catch(RuntimeException x) {
				System.out.println("SCC: " + x.toString());
				lastException = x;
			}

			if(tries++ > 5 || System.currentTimeMillis() > ets) {
				throw lastException;
			}
			try {
				Thread.sleep(1000);
			} catch(InterruptedException e) {
				//-- Idiots.
			}
			System.out.println("Retrying transact packet: " + lastException.getMessage());
		}
	}

	private int readByte() {
		if(m_rdBufIndex >= m_rdBufLen) {
			throw new RxDataException("Read past end of packet");
		}
		int val = m_rdbuf[m_rdBufIndex++] & 0xff;
		return val;
	}

	private int readWord() {
		int high = readByte();
		int low = readByte();
		return high << 8 | low;
	}

	private String readString() {
		StringBuilder sb = new StringBuilder();
		while(m_rdBufIndex < m_rdBufLen) {
			int c = m_rdbuf[m_rdBufIndex++] & 0xff;
			if((c >= 0x20 && c < 0x80) || c == '\n') {
				sb.append((char) c);
			}
		}
		return sb.toString();
	}

	private byte[] m_rdbuf = new byte[256 + 4];

	private int m_rdBufIndex;

	private int m_rdBufLen;

	static private final long PACKET_READ_TIMEOUT = 5 * 1000L;

	static private final long RETRY_TIMEOUT = 30 * 1000L;

	private final StringBuilder m_rxSb = new StringBuilder();

	private void receivePacket() {
		long ets = System.currentTimeMillis() + PACKET_READ_TIMEOUT;
		m_rxSb.setLength(0);

		//-- Wait for the 0xaa 0x55
		int phase = 0;
		for(; ; ) {
			int rl = m_port.readBytes(m_rdbuf, 1, 0);
			if(rl == 1) {
				//System.out.println("BYTE: " + (char) m_rdbuf[0] + " " + m_rdbuf[0]);
				if((m_rdbuf[0] & 0xff) == 0xaa) {
					phase = 1;
				} else if(m_rdbuf[0] == 0x55 && phase == 1) {
					break;
				} else {
					char c = (char) m_rdbuf[0];
					if(c >= 0x20 && c < 0x80) {
						m_rxSb.append((char) c);
					} else if(c == 0x0a) {
						System.out.println("ArduinoDebug: " + m_rxSb);
						m_rxSb.setLength(0);
					}
				}
			}

			if(System.currentTimeMillis() > ets) {
				throw new MessageException("Read timed out during header prefix read");
			}
		}

		//-- Prefix found. Read length
		int rl = m_port.readBytes(m_rdbuf, 1, 0);
		if(rl != 1)
			throw new MessageException("Length not received");
		int len = m_rdbuf[0] & 0xff;

		int offset = 0;
		int todo = len + 2;

		while(todo > 0) {
			rl = m_port.readBytes(m_rdbuf, todo, offset);
			if(rl < 0)
				throw new MessageException("eof during serial read");
			todo -= rl;
			offset += rl;
		}

		//-- Checksum the packet
		int sum = 0;
		for(int i = 0; i < len; i++) {
			sum += m_rdbuf[i] & 0xff;
		}
		int hilen = m_rdbuf[len] & 0xff;
		int lolen = m_rdbuf[len + 1] & 0xff;

		if(hilen != ((sum >> 8) & 0xff) || lolen != (sum & 0xff)) {
			throw new MessageException("Checksum error");
		}

		m_rdBufLen = len;
		m_rdBufIndex = 0;
	}


	/**
	 * Send the packet over the serial link.
	 */
	private void sendPacket(byte[] packet) {
		int rc = m_port.writeBytes(packet, packet.length);
		if(rc != packet.length) {
			throw new MessageException("Packet write error: wrote " + rc + " but expected " + packet.length);
		}
	}



	/*----------------------------------------------------------------------*/
	/*	CODING:	Primitive packet construction								*/
	/*----------------------------------------------------------------------*/

	private void startPacket(int command) {
		m_lastCommand = command;
		writeWord(command);
	}

	private void writeWord(int b) {
		ByteArrayOutputStream pb = pb();
		pb.write(b >> 8);
		pb.write(b & 0xff);
		m_packetLen += 2;
	}

	private void writeByte(int b) {
		pb().write(b);
		m_packetLen++;
	}
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

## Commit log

2025-11-23 Initial commit.
    [aluboard.kicad_pcb, aluboard.kicad_sch, busmodule.kicad_sch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]
2025-11-23 Redoing control board because of pipeline blunder. This also is the last version with the distinct program counter.
    [aluboard.kicad_sch, busmodule.kicad_sch, cpu1.kicad_sch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]
2025-11-24 [control] work in progress
    [busmodule.kicad_sch]
2025-11-28 [alucontroller] Add initial version of ALU board controller, showing register contents only
2025-11-28 [aluboard] Add Arduino tester application for alucontroller
2025-11-28 [aluboard] Arduino IDE wants a different name.
2025-11-29 [aluboard] Fixes, added read/update registers functions and buttons
    [SerialApi.java, aluboard-arduino.ino]
2025-11-30 [aluboard] Add alu operation UI
    [aluboard.kicad_sch]
2025-11-30 [aluboard] first-run fixes for alu operation ui
    [SerialApi.java, aluboard-arduino.ino]
2025-12-14 [aluboard] Fix remarks
    [aluboard.kicad_sch]
2025-12-21 [alu] Show flag values.
    [aluboard.kicad_sch]

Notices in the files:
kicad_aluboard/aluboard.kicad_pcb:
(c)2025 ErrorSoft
